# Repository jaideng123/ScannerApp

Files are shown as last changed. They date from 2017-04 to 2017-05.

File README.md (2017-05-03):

# ScannerApp
This is the android application for the automated microfilm scanner
This repository also contains the code for the arduino that we use to control the solenoids and motors as well as communicate with the phone via an HC-05 Bluetooth module

Project Video: https://www.youtube.com/watch?v=Uh_XvRmYF0I

Materials:

* Solenoid x2 : https://www.amazon.com/gp/product/B00J2N2QOY/ref=oh_aui_detailpage_o07_s01?ie=UTF8&psc=1
* 28-BYJ 12v Stepper Motor x2 : https://www.ebay.com/p/?iid=172294403078&lpid=82&&&ul_noapp=true&chn=ps
* ULN2003 Driver Board x2 : https://solarbotics.com/product/22315/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
* Arduino Uno : https://www.amazon.com/Arduino-Uno-Rev-3-A000066/dp/B006H06TVG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
* TIP120 Transistor x2 : https://www.amazon.com/gp/product/B01HQ06CCG/ref=oh_aui_detailpage_o07_s02?ie=UTF8&psc=1
* 12v battery pack x2 : https://www.amazon.com/gp/product/B00VE7HBMS/ref=oh_aui_search_detailpage?ie=UTF8&psc=1
* Aukey Ora Lens : https://www.amazon.com/gp/product/B01ID3YDC6/ref=oh_aui_search_detailpage?ie=UTF8&psc=1
* Breadboad : https://www.amazon.com/microtivity-400-point-Experiment-Breadboard-Jumper/dp/B004RXKWDQ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
* Backlight : https://www.amazon.com/Arducam-Display-Controller-Character-Backlight/dp/B019D9TYMI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 (We stripped the cover and just used the backlight)
* HC-05 Bluetooth module : https://www.amazon.com/HC-05-Bluetooth-Pass-through-Wireless-Communication/dp/B01G9KSAF6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

Solenoid wiring: http://www.instructables.com/id/Controlling-solenoids-with-arduino/

HC-05 Wiring: https://cdn.instructables.com/FXV/32RA/I8SLPA3L/FXV32RAI8SLPA3L.MEDIUM.jpg

The mounts were 3D-printed using solidworks, the files are under the Final-3D-Designs directory and could use some reworking as it was very hard to fit the screws into some of them

the solenoids can be a little tempermental so just give them a gentle nudge if they dont engage

If you have any questions or need any assistance getting the project running email me at jaideng123@yahoo.com

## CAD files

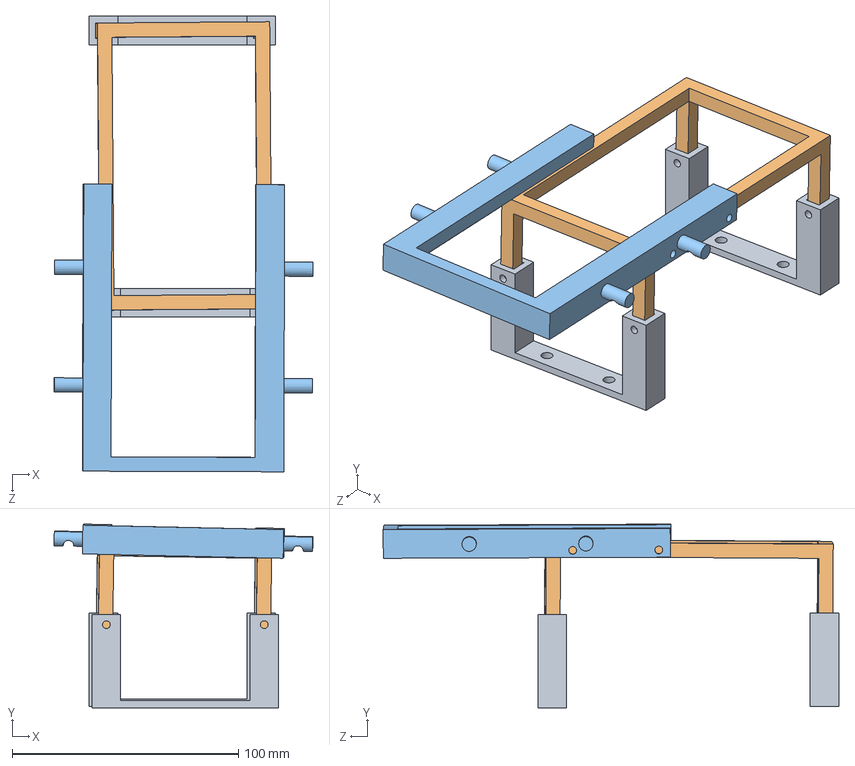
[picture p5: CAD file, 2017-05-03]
Final-3D-Designs/Assem1.SLDASM
114.6 x 81.3 x 201.6 mm
PhoneHolderMount x 2
PhoneHolder
PhoneSlide

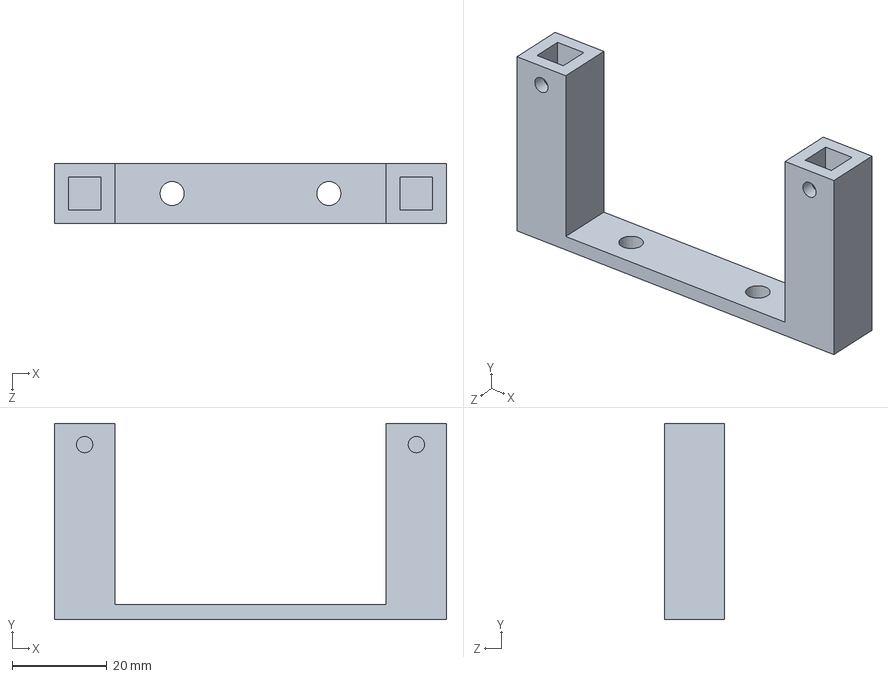
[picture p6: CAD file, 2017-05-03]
Final-3D-Designs/PhoneHolderMount.SLDPRT
82.5 x 41.3 x 12.7 mm

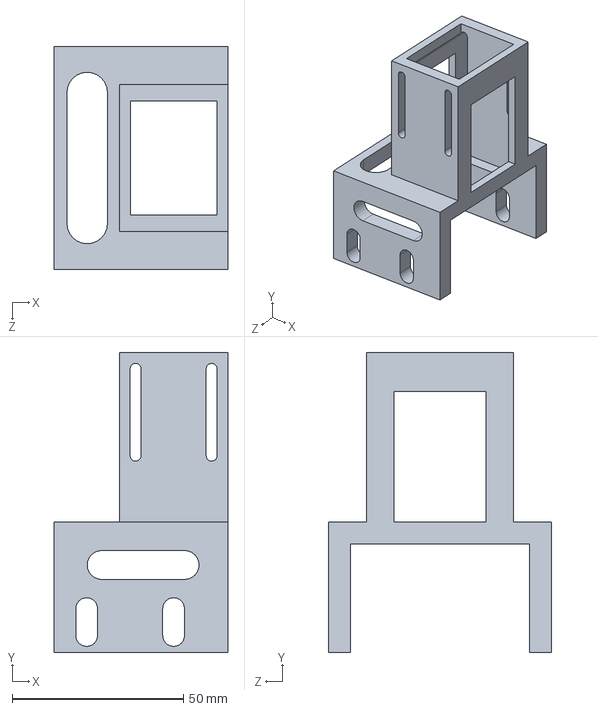
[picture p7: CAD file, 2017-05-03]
Final-3D-Designs/Solenoid.SLDPRT
50.8 x 87.6 x 65.1 mm

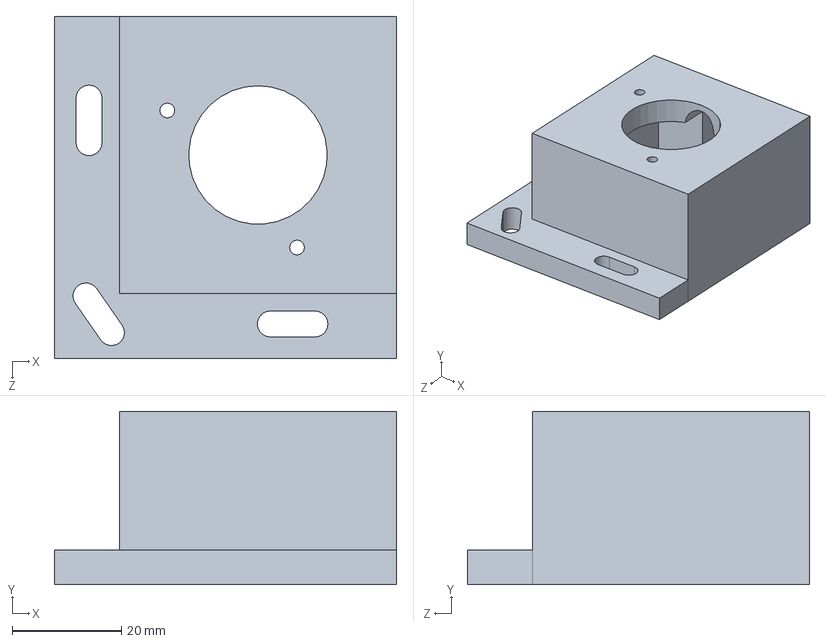
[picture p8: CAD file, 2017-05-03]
Final-3D-Designs/MotorBox.SLDPRT
62.7 x 31.8 x 62.7 mm

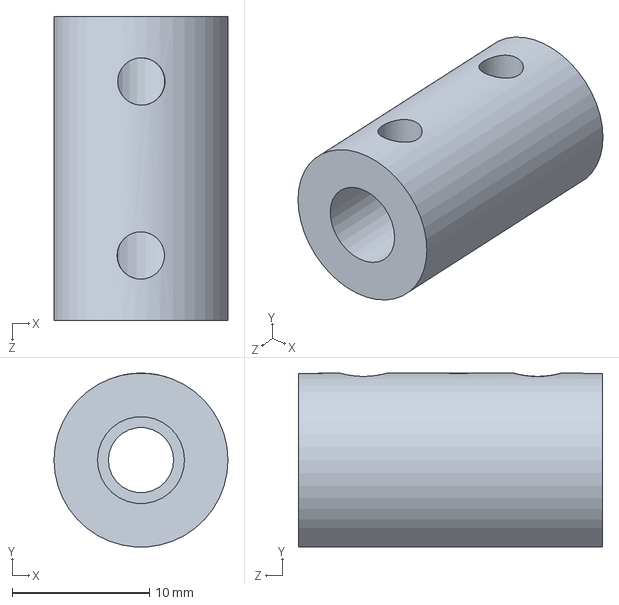
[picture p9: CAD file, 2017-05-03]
Final-3D-Designs/SlideConverter.SLDPRT
12.7 x 12.7 x 22.2 mm

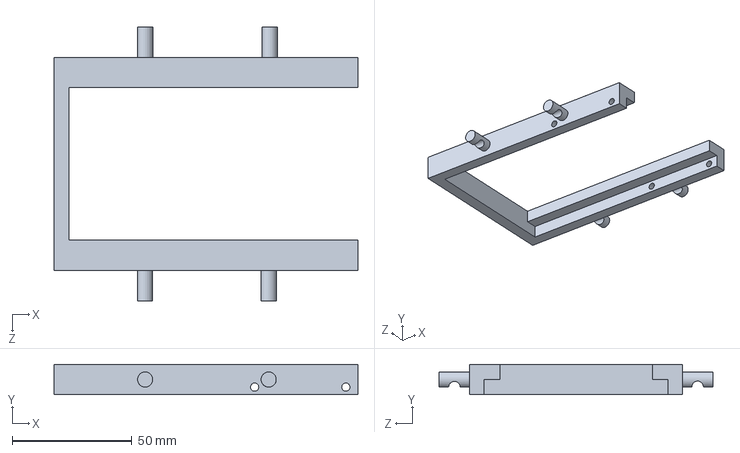
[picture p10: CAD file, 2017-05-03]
Final-3D-Designs/PhoneSlide.SLDPRT
127.0 x 12.7 x 114.3 mm

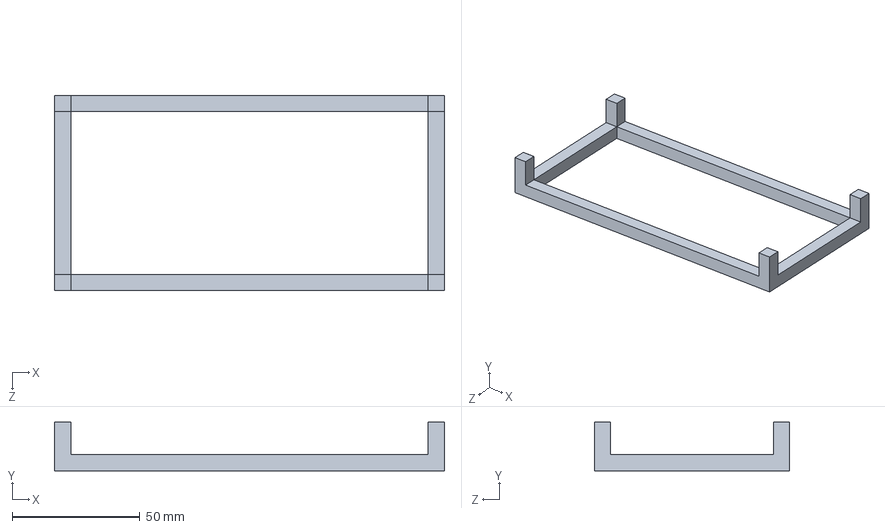
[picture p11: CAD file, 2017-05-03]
Final-3D-Designs/PhoneHolder.SLDPRT
152.4 x 19.0 x 76.2 mm

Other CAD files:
Final-3D-Designs/MotorBox.SLDDRW
Final-3D-Designs/SlideConverter.SLDDRW

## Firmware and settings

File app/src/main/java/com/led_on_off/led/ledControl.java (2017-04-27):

package com.led_on_off.led;

import android.hardware.Camera;
import android.os.Environment;
import android.os.Handler;
import android.support.v7.app.ActionBarActivity;
import android.os.Bundle;
import android.util.Log;
import android.view.Menu;
import android.view.MenuItem;

import android.bluetooth.BluetoothSocket;
import android.content.Intent;
import android.view.MotionEvent;
import android.view.View;
import android.view.ViewGroup;
import android.view.WindowManager;
import android.widget.FrameLayout;
import android.widget.ImageButton;
import android.widget.ImageView;
import android.widget.Toast;
import android.app.ProgressDialog;
import android.bluetooth.BluetoothAdapter;
import android.bluetooth.BluetoothDevice;
import android.os.AsyncTask;

import java.io.File;
import java.io.FileOutputStream;
import java.io.IOException;
import java.text.SimpleDateFormat;
import java.util.Date;
import java.util.UUID;

import static java.lang.Thread.sleep;

public class ledControl extends ActionBarActivity {
    private int inactive = 0x8056B3CD;
    private int active = 0x8056cdab;
    private boolean pressedDown = false;
   // Button btnOn, btnOff, btnDis;
    ImageButton Play, Discnt;

    String address = null;
    private ProgressDialog progress;
    BluetoothAdapter myBluetooth = null;
    BluetoothSocket btSocket = null;
    private boolean isBtConnected = false;
    private Camera c = null;
    private CameraPreview mPreview = null;
    ImageView top = null;
    ImageView bot = null;
    public static int currentTopY = 0;
    public static int currentBotY = 0;
    boolean topBarBlack = false;
    boolean botBarBlack = false;
    boolean openCamera = false;
    boolean isMoving = false;
    boolean playing = false;
    boolean safePic = true;
    //SPP UUID. Look for it
    static final UUID myUUID = UUID.fromString("00001101-0000-1000-8000-00805F9B34FB");
    Handler handler = new Handler();

    static public void decodeYUV420SP(int[] rgb, byte[] yuv420sp, int width, int height) {
        final int frameSize = width * height;

        for (int j = 0, yp = 0; j < height; j++) {
            int uvp = frameSize + (j >> 1) * width, u = 0, v = 0;
            for (int i = 0; i < width; i++, yp++) {
                int y = (0xff & ((int) yuv420sp[yp])) - 16;
                if (y < 0) y = 0;
                if ((i & 1) == 0) {
                    v = (0xff & yuv420sp[uvp++]) - 128;
                    u = (0xff & yuv420sp[uvp++]) - 128;
                }

                int y1192 = 1192 * y;
                int r = (y1192 + 1634 * v);
                int g = (y1192 - 833 * v - 400 * u);
                int b = (y1192 + 2066 * u);

                if (r < 0) r = 0; else if (r > 262143) r = 262143;
                if (g < 0) g = 0; else if (g > 262143) g = 262143;
                if (b < 0) b = 0; else if (b > 262143) b = 262143;

                rgb[yp] = 0xff000000 | ((r << 6) & 0xff0000) | ((g >> 2) & 0xff00) | ((b >> 10) & 0xff);
            }
        }
    }

    @Override
    protected void onCreate(Bundle savedInstanceState)
    {
        super.onCreate(savedInstanceState);

        Intent newint = getIntent();
        address = newint.getStringExtra(DeviceList.EXTRA_ADDRESS); //receive the address of the bluetooth device

        //view of the ledControl
        setContentView(R.layout.activity_led_control);

        //call the widgets
        Play = (ImageButton)findViewById(R.id.play);
        Discnt = (ImageButton)findViewById(R.id.discnt);
        getWindow().setFlags(WindowManager.LayoutParams.FLAG_FULLSCREEN,
                WindowManager.LayoutParams.FLAG_FULLSCREEN);


        new ConnectBT().execute(); //Call the class to connect

        //commands to be sent to bluetooth
        Play.setOnClickListener(new View.OnClickListener()
        {
            @Override
            public void onClick(View v)
            {
                playFunc();      //method to turn on
            }
        });

        Discnt.setOnClickListener(new View.OnClickListener()
        {
            @Override
            public void onClick(View v)
            {
                Disconnect(); //close connection
            }
        });

        try{
            c = Camera.open();
            c.setDisplayOrientation(90);
        }
        catch(Exception e){

        }
        Camera.Parameters params = c.getParameters();
        params.setPictureSize(1920,1080);
        c.setParameters(params);
        mPreview = new CameraPreview(this, c, ledControl.this);
        FrameLayout preview = (FrameLayout)findViewById(R.id.camera_preview);
        preview.addView(mPreview);
        top = (ImageView) findViewById(R.id.topBox);
        bot = (ImageView) findViewById(R.id.bottomBox);
        Camera.Size dimensions = c.getParameters().getPreviewSize();
        setMargins(top,0,100,0,0);
        setMargins(bot,0,dimensions.width-400,0,0);
        currentTopY = 100;
        currentBotY = dimensions.width-400;
        handler.post(runnableCode);
        handler.post(movingCode);
        File folder = new File(Environment.getExternalStorageDirectory() +
                File.separator + "ScannerApp");
        boolean success = true;
        if (!folder.exists()) {
            success = folder.mkdirs();
        }
    }
    private Runnable runnableCode = new Runnable() {
        @Override
        public void run() {
            Log.d("Handlers", "Called on main thread");
            if(playing)
                openCamera = true;
            handler.postDelayed(runnableCode, 1000);
        }
    };
    private Runnable movingCode = new Runnable() {
        @Override
        public void run() {
            Log.d("Handlers", "Moving reel");
            if(isMoving)
                try {
                    btSocket.getOutputStream().write('1');
                } catch (IOException e) {
                    e.printStackTrace();
                }
            handler.postDelayed(movingCode, 480);
        }
    };

    private void Disconnect()
    {
        if (btSocket!=null) //If the btSocket is busy
        {
            try
            {
                btSocket.close(); //close connection
            }
            catch (IOException e)
            { msg("Error");}
        }
        finish(); //return to the first layout

    }

    private void playFunc()
    {
        if (btSocket!=null)
        {
            isMoving = true;
            playing = true;
        }
    }

    // fast way to call Toast
    private void msg(String s)
    {
        Toast.makeText(getApplicationContext(),s,Toast.LENGTH_LONG).show();
    }

    @Override
    public boolean onCreateOptionsMenu(Menu menu) {
        // Inflate the menu; this adds items to the action bar if it is present.
        getMenuInflater().inflate(R.menu.menu_led_control, menu);
        return true;
    }
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

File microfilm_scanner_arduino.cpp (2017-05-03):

// This is the code that's run on the arduino
#include <AccelStepper.h>
#include <QueueArray.h>
#define HALFSTEP 8

// motor pins
#define motorPin1  4     // IN1 on the ULN2003 driver 1
#define motorPin2  5     // IN2 on the ULN2003 driver 1
#define motorPin3  6     // IN3 on the ULN2003 driver 1
#define motorPin4  7     // IN4 on the ULN2003 driver 1

#define motorPin5  8     // IN1 on the ULN2003 driver 2
#define motorPin6  9     // IN2 on the ULN2003 driver 2
#define motorPin7  10    // IN3 on the ULN2003 driver 2
#define motorPin8  11    // IN4 on the ULN2003 driver 2
#define solenoidPinl 3    //output pin of left solenoid
#define solenoidPinr 2    //output pin of right solenoid


// Initialize with pin sequence IN1-IN3-IN2-IN4 for using the AccelStepper with 28BYJ-48
AccelStepper stepper1(HALFSTEP, motorPin1, motorPin3, motorPin2, motorPin4);//Left Motor
AccelStepper stepper2(HALFSTEP, motorPin5, motorPin7, motorPin6, motorPin8);//Right Motor

// variables
int turnSteps = 5; // number of steps to move forward each time
int lineSteps = -5; //number of steps to move backward each time
int stepperSpeed = 1000; //speed of the stepper (steps per second)
int steps1 = 0; // keep track of the step count for motor 1
int steps2 = 0; // keep track of the step count for motor 2
bool leftDisabled = false;
bool rightDisabled = false;
unsigned long previousMillis = 0; // last time update
long interval = 5000; // interval at which to do something (milliseconds)
QueueArray <char> queue; 

void disableGear(char x){
  //Disable Left Gear
  if(x == 'L'){
      leftDisabled = true;
      rightDisabled = false;
      digitalWrite(solenoidPinl, LOW);
      digitalWrite(solenoidPinr, HIGH);
  }
  //Disable Right Gear
  else if(x == 'R'){
      leftDisabled = false;
      rightDisabled = true;
      digitalWrite(solenoidPinr, LOW);
      digitalWrite(solenoidPinl, HIGH);
  }
  else if(x == 'B'){
    leftDisabled = false;
    rightDisabled = false;
    digitalWrite(solenoidPinr, LOW);
    digitalWrite(solenoidPinl, LOW);
  }
//  

  delay(400);
}

void setup() {
  Serial.begin(9600);
  pinMode(solenoidPinl, OUTPUT);           //Sets the pin as an output
  pinMode(solenoidPinr, OUTPUT);           //Sets the pin as an output
  stepper1.setMaxSpeed(2000.0);
  stepper1.move(1);  // I found this necessary
  stepper1.setSpeed(stepperSpeed);
  stepper2.setMaxSpeed(2000.0);
  stepper2.move(1);  // I found this necessary
  stepper2.setSpeed(stepperSpeed);
//   queue.enqueue('1');
//   queue.enqueue('1');
//   queue.enqueue('1');
//   queue.enqueue('3');
//   queue.enqueue('3');
//   queue.enqueue('3');
  

}
void loop() {
  if(Serial.available() > 0)      // Send data only when you receive data:
  {
      int data = Serial.read();        //Read the incoming data & store into data
      Serial.print(data);          //Print Value inside data in Serial monitor
      Serial.print("\n");
      //Clear our queue
      if(data == 'C'){
        while(!queue.isEmpty()){
          queue.dequeue();
        }
      }
      else if(queue.count() < 100){
        queue.enqueue(data);
      }
      
  }
  char current = 0;
  //when we're not working on anything, grab the next instruction
  if(steps1 == 0 && steps2 == 0 && !queue.isEmpty()){
    current = queue.dequeue();
    previousMillis = millis();
    Serial.print(current);          //Print Value inside data in Serial monitor
    Serial.print("\n");
  }
  else if(millis()-previousMillis > interval){
    disableGear('B');
    stepper1.disableOutputs();
    stepper2.disableOutputs();
    previousMillis = millis();
  }
  
  //Move Left Gear Clockwise
  if (current == '1') {
    if(!rightDisabled){
      disableGear('R');
    }
    stepper1.enableOutputs();
    int target = turnSteps;
    stepper1.move(target);
    stepper1.setSpeed(stepperSpeed);
  }
  //Move Left Gear Counter-Clockwise
  else if(current == '2'){
    if(!rightDisabled){
      disableGear('R');
    }
    stepper1.enableOutputs();
    int target = lineSteps;
    stepper1.move(target);
    stepper1.setSpeed(stepperSpeed);
  }
  //Move Right Gear Clockwise
  if (current == '3') {
    if(!leftDisabled){
      disableGear('L');
    }
    stepper2.enableOutputs();
    int target = turnSteps;
    stepper2.move(target);
    stepper2.setSpeed(stepperSpeed);
  }
  //Move Right Gear Counter-Clockwise
  else if(current == '4'){
    if(!leftDisabled){
      disableGear('L');
    }
    stepper2.enableOutputs();
    int target = lineSteps;
    stepper2.move(target);
    stepper2.setSpeed(stepperSpeed);
  }
  //Disable Left Or Right Gear
  else if(current == 'L' || current == 'R'){
    disableGear(current);
  }

  steps1 = stepper1.distanceToGo();
  steps2 = stepper2.distanceToGo();

  stepper1.runSpeedToPosition();
  stepper2.runSpeedToPosition();
}

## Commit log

2017-04-20 We can now get pixel values out of the camera preview
2017-05-03 Added arduino code
